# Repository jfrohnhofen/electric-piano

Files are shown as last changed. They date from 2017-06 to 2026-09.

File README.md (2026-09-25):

# Electric Piano

This repository contains the hardware and software sources for a custom electric piano project built around the ATmega16 microcontroller.

## Project Structure

The project is divided into the following main directories:

- **circuit/**: Contains the hardware design files.
  - `eagle/`: Schematics and PCB layouts designed in EAGLE.
  - `gerber/`: Manufacturing files for the PCB.
  - `parts.txt`: Bill of materials (BOM).
  - `stencil.svg`: Stencil design for solder paste application.

- **firmware/**: The C++ firmware running on the ATmega16 (16MHz).
  - `firmware.cpp`: Main application code.
  - `bootloader.cpp`: Custom bootloader.
  - `runfile`: Build and flash instructions using `avr-g++` and `avrdude` via STK500v1 over serial.

- **programer/**: A custom programmer utility written in Rust.

## Prerequisites

The easiest way to get started is by using the provided Nix flake. If you have [Nix](https://nixos.org/) installed, simply run:

```bash
nix develop
```

This will drop you into a development shell with all the required dependencies (`avr-gcc`, `avrdude`, `cargo`, `just`, etc.) installed.

If you are not using Nix, you will need to manually install:
- `avr-gcc` / `avr-g++`
- `avr-libc`
- `avrdude`
- Rust toolchain (`cargo`)
- [`just`](https://github.com/casey/just) command runner

## Building and Flashing

This project uses `just` as a command runner. You can see all available commands by running:

```bash
just --list
```

From the root directory, you can run:

- Compile the bootloader: `just bootloader`
- Compile the firmware: `just firmware`
- Flash the bootloader: `just flash-bootloader`
- Write fuses: `just write-fuses`
- Build the Rust programmer: `just build-programmer`
- Run the Rust programmer: `just run-programmer`
- Build everything: `just build-all`

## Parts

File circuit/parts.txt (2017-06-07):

Partlist

Exported from epiano.sch at 8/28/2015 8:06 PM

EAGLE Version 7.3.0 Copyright (c) 1988-2015 CadSoft

Assembly variant: 

Part     Value                Device               Package     Library  Sheet

6N138    6N138                6N138                SMD-8       epiano   1
4067     4067D                4067D                SO24W       40xx     1
C1       22pF                 C-EUC0805            C0805       epiano   1
C2       22pF                 C-EUC0805            C0805       epiano   1
C3       100nF                C-EUC0805            C0805       epiano   1
C4       47uF                 CPOL-EUD             PANASONIC_D rcl      1
C5       47uF                 CPOL-EUD             PANASONIC_D rcl      1
C6       100nF                C-EUC0805            C0805       epiano   1
C7       100nF                C-EUC0805            C0805       epiano   1
D1       1N4001               DIODE-MELF-MLL41     MELF-MLL41  diode    1
D2       1N4001               DIODE-MELF-MLL41     MELF-MLL41  diode    1
D3       1N4148               DIODE-MINIMELF       MINIMELF    diode    1
DC       DCJ0202              DCJ0202              DCJ0202     epiano   1
ISP      ISP                  PINHD-2X5_2.54-SMD   2X05SMD     epiano   1
LEFT     KBD_LEFT             PINHD-2X10_2.54-SMD  2X10SMD     epiano   1
LM1117   MC33269ST-3.3T3      MC33269ST-3.3T3      SOT223      epiano   1
MEGA16   MEGA16-A             MEGA16-A             TQFP44      atmel    1
MIDI     MAB5SH               MAB5SH               MAB5SH      epiano   1
MIDIMATE                      USBMIDI_2.54-SMD     USBMIDI     epiano   1
PEDAL    PEDAL                PINHD-2X4_2.54-SMD   2X04SMD     epiano   1
Q1       16MHz                CRYSTALSM49          SM49        crystal  1
R1       10k?                 R-EU_R0805           R0805       epiano   1
R2       220?                 R-EU_R0805           R0805       epiano   1
R3       220?                 R-EU_R0805           R0805       epiano   1
R4       220?                 R-EU_R0805           R0805       epiano   1
R5       1k?                  R-EU_R0805           R0805       epiano   1
R6       0?                   R-EU_R1206           R1206       epiano   1
RIGHT    KBD_RIGHT            PINHD-2X10_2.54-SMD  2X10SMD     epiano   1
USB      MINI-USB-UX60-MB-5ST MINI-USB-UX60-MB-5ST UX60-MB-5ST epiano   1

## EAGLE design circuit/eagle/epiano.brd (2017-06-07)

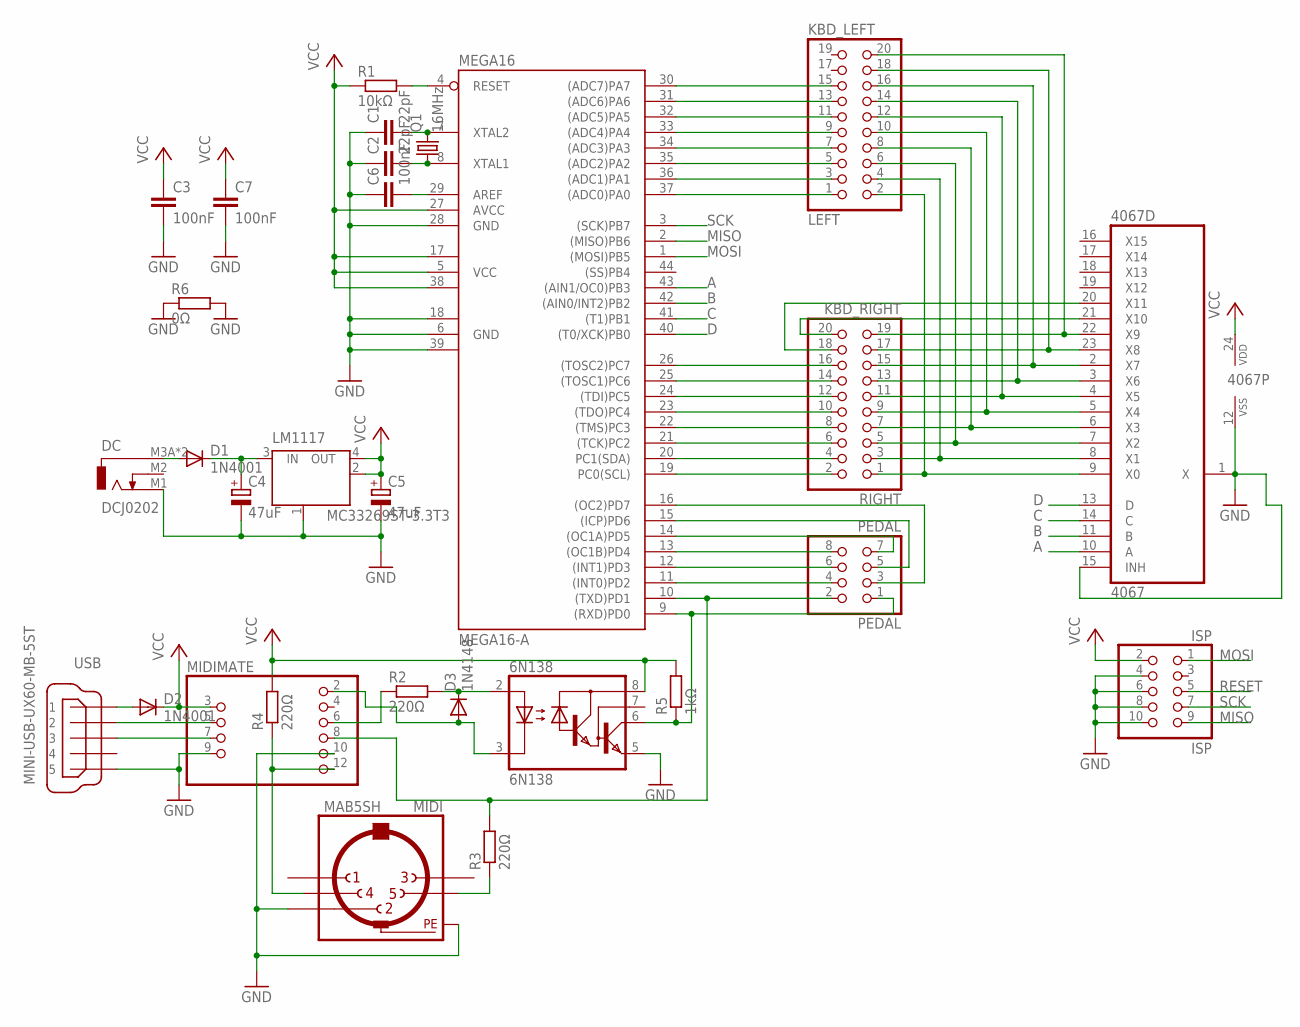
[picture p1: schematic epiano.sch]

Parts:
6N138: 6N138; SMD-8
4067: 4067D; SO24W
C1, C2: 22pF; C0805
C3, C6, C7: 100nF; C0805
C4, C5: 47uF; PANASONIC_D
D1, D2: 1N4001; MELF-MLL41
D3: 1N4148; MINIMELF
DC: DCJ0202
ISP: ISP; 2X05SMD
LEFT: KBD_LEFT; 2X10SMD
LM1117: MC33269ST-3.3T3; SOT223
MEGA16: MEGA16-A; TQFP44
MIDI: MAB5SH
MIDIMATE: USBMIDI_2.54-SMD; USBMIDI
PEDAL: PEDAL; 2X04SMD
Q1: 16MHz; SM49
R1: 10kΩ; R0805
R2, R3, R4: 220Ω; R0805
R5: 1kΩ; R0805
R6: 0Ω; R1206
RIGHT: KBD_RIGHT; 2X10SMD
USB: MINI-USB-UX60-MB-5ST; UX60-MB-5ST

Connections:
A: 4067.10 (A), MEGA16.43 ((AIN1/OC0)PB3)
B: 4067.11 (B), MEGA16.42 ((AIN0/INT2)PB2)
C: 4067.14 (C), MEGA16.41 ((T1)PB1)
D: 4067.13 (D), MEGA16.40 ((T0/XCK)PB0)
GND: 6N138.5 (GND), 4067.1 (X), 4067.12 (VSS), 4067.15 (INH), C1.1, C2.1, C3.2, C4.-, C5.-, C6.1, C7.2, DC.M1 (3), ISP.4, ISP.6, ISP.8, ISP.10, LM1117.1 (GND/ADJ), MEGA16.6 (GND), MEGA16.18 (GND1), MEGA16.28 (GND), MEGA16.39 (GND2), MIDI.2, MIDI.PE, MIDI.PE@ (PE), MIDIMATE.9, MIDIMATE.10, R6.1, R6.2, USB.5
MISO: ISP.9, MEGA16.2 ((MISO)PB6)
MOSI: ISP.1, MEGA16.1 ((MOSI)PB5)
unnamed: D2.A, USB.1
unnamed: MIDIMATE.5, USB.2
unnamed: C2.2, MEGA16.8 (XTAL1), Q1.1
unnamed: C4.+, D1.C, LM1117.3 (IN)
unnamed: MEGA16.19 (PC0(SCL)), RIGHT.2
unnamed: MEGA16.20 (PC1(SDA)), RIGHT.4
unnamed: MEGA16.21 ((TCK)PC2), RIGHT.6
unnamed: D1.A, DC.M3A (1), DC.M3B (1)
unnamed: MEGA16.22 ((TMS)PC3), RIGHT.8
unnamed: MEGA16.23 ((TDO)PC4), RIGHT.10
unnamed: MEGA16.24 ((TDI)PC5), RIGHT.12
unnamed: MEGA16.25 ((TOSC1)PC6), RIGHT.14
unnamed: MEGA16.26 ((TOSC2)PC7), RIGHT.16
unnamed: 4067.20 (X11), RIGHT.18
unnamed: LEFT.1, MEGA16.37 ((ADC0)PA0)
unnamed: LEFT.3, MEGA16.36 ((ADC1)PA1)
unnamed: LEFT.5, MEGA16.35 ((ADC2)PA2)
unnamed: LEFT.7, MEGA16.34 ((ADC3)PA3)
unnamed: LEFT.9, MEGA16.33 ((ADC4)PA4)
unnamed: LEFT.11, MEGA16.32 ((ADC5)PA5)
unnamed: LEFT.13, MEGA16.31 ((ADC6)PA6)
unnamed: LEFT.15, MEGA16.30 ((ADC7)PA7)
unnamed: 4067.21 (X10), RIGHT.20
unnamed: 4067.9 (X0), LEFT.2, RIGHT.1
unnamed: 4067.8 (X1), LEFT.4, RIGHT.3
unnamed: 4067.7 (X2), LEFT.6, RIGHT.5
unnamed: 4067.6 (X3), LEFT.8, RIGHT.7
unnamed: 4067.5 (X4), LEFT.10, RIGHT.9
unnamed: 4067.4 (X5), LEFT.12, RIGHT.11
unnamed: 4067.3 (X6), LEFT.14, RIGHT.13
unnamed: 4067.2 (X7), LEFT.16, RIGHT.15
unnamed: 4067.23 (X8), LEFT.18, RIGHT.17
unnamed: 4067.22 (X9), LEFT.20, RIGHT.19
unnamed: MEGA16.10 ((TXD)PD1), MIDIMATE.8, PEDAL.2, R3.2
unnamed: C6.2, MEGA16.29 (AREF)
unnamed: MEGA16.11 ((INT0)PD2), PEDAL.4
unnamed: MEGA16.12 ((INT1)PD3), PEDAL.6
unnamed: C1.2, MEGA16.7 (XTAL2), Q1.2
unnamed: MIDIMATE.7, USB.3
unnamed: MIDIMATE.6, R2.1
unnamed: MEGA16.13 ((OC1B)PD4), PEDAL.8
unnamed: MIDI.4, MIDIMATE.12, R4.1
unnamed: 6N138.3 (C), D3.A, MIDIMATE.2
unnamed: MEGA16.14 ((OC1A)PD5), PEDAL.7
unnamed: MEGA16.15 ((ICP)PD6), PEDAL.5
unnamed: MEGA16.16 ((OC2)PD7), PEDAL.3
unnamed: MIDI.5, R3.1
unnamed: 6N138.2 (A), D3.C, R2.2
unnamed: 6N138.6 (VO), MEGA16.9 ((RXD)PD0), PEDAL.1, R5.1
RESET: ISP.5, MEGA16.4 (RESET), R1.2
SCK: ISP.7, MEGA16.3 ((SCK)PB7)
VCC: 6N138.8 (VCC), 4067.24 (VDD), C3.1, C5.+, C7.1, D2.C, ISP.2, LM1117.2 (OUT), LM1117.4 (OUT), MEGA16.5 (VCC), MEGA16.17 (VCC1), MEGA16.27 (AVCC), MEGA16.38 (VCC2), MIDIMATE.3, R1.1, R4.2, R5.2

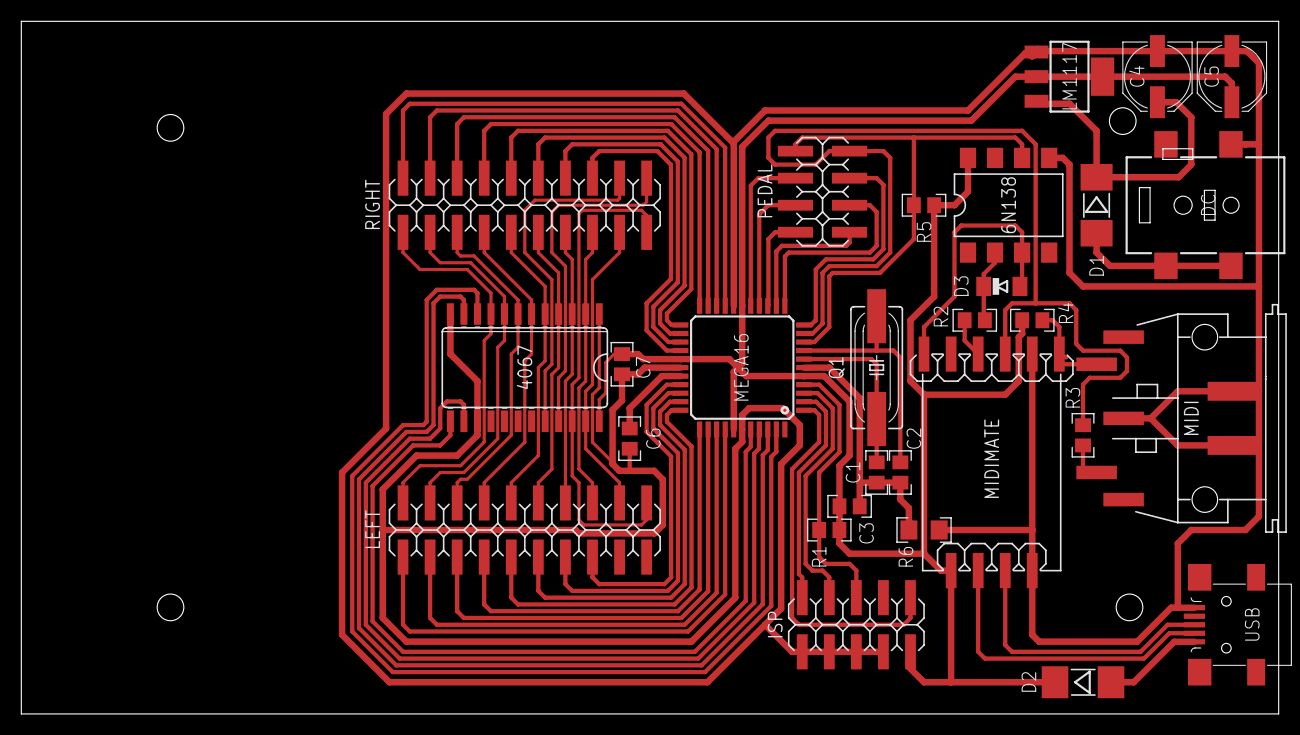
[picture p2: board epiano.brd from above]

Board: 1 copper layer, 118.0 x 65.0 mm, 29 parts (0 on the bottom side), 59 nets.

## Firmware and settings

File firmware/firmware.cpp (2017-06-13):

// The MIT License (MIT)
//
// Copyright (c) 2016 Johannes Frohnhofen
//
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
// -----------------------------------------------------------------------------
//

#include <avr/io.h>
#include <avr/interrupt.h>
#include <avr/pgmspace.h>
#include <util/delay.h>

#define MIDI_BAUD_RATE     31250

#define MIDI_A0            0x15
#define MIDI_NOTE_ON       0x90
#define MIDI_NOTE_OFF      0x80
#define MIDI_CONTROL       0xb0
#define MIDI_PROGRAM       0xc0
#define MIDI_SUSTAIN_PEDAL 0x40
#define MIDI_SOFT_PEDAL    0x43

#define SUSTAIN_PEDAL      PD3
#define SOFT_PEDAL         PD4

#define for_set_bits(BIT, VAR) \
  for(uint8_t BIT=0; VAR>0; BIT++, VAR>>=1) \
    if(VAR & 1)

#define min(a, b) ((a) < (b) ? (a) : (b))

#define KEY_INDEX(CHANNEL, LINE) (((LINE) >> 3) * 0x28 + ((CHANNEL) << 3) + ((LINE) & 0b111))

#define MIDI_KEY(CHANNEL, LINE) (MIDI_A0 + KEY_INDEX(CHANNEL, LINE))

#define READ_LINES(CHANNEL, VAR) \
  PORTB = channel_addr[(CHANNEL)]; \
  _delay_us(30); \
  VAR = (PINC << 8) | PINA;

#define HANDLE_PEDAL(PIN, COMMAND) \
  if(pedals & _BV(PIN)) { \
    uart_putc(MIDI_CONTROL); \
    uart_putc(COMMAND); \
    uart_putc((stateP & _BV(PIN)) << (6 - (PIN))); \
    _delay_ms(2); \
  }

const uint8_t channel_addr[] = {
  0b0000, 0b1000, 0b0100, 0b1100, 0b0010, 0b1010,
  0b0110, 0b1110, 0b0001, 0b1001, 0b0101, 0b1101
};

const uint8_t velocities[] PROGMEM = {
  0x7f, 0x7f, 0x7f, 0x7f, 0x7f, 0x7f, 0x7f, 0x7f, 0x7f, 0x7f, 0x7f, 0x7f, 0x7f, 0x7f, 0x7f, 0x7f,
  0x7f, 0x7f, 0x7f, 0x7f, 0x7f, 0x7f, 0x7f, 0x7f, 0x7f, 0x7f, 0x7f, 0x7f, 0x7f, 0x7f, 0x7f, 0x7e,
  0x7d, 0x7b, 0x7a, 0x78, 0x77, 0x75, 0x74, 0x73, 0x72, 0x71, 0x70, 0x6f, 0x6e, 0x6d, 0x6c, 0x6b,
  0x6a, 0x69, 0x68, 0x67, 0x66, 0x66, 0x65, 0x64, 0x63, 0x63, 0x62, 0x61, 0x61, 0x60, 0x5f, 0x5f,
  0x5e, 0x5e, 0x5d, 0x5d, 0x5c, 0x5b, 0x5b, 0x5a, 0x5a, 0x59, 0x59, 0x58, 0x58, 0x57, 0x57, 0x57,
  0x56, 0x56, 0x55, 0x55, 0x54, 0x54, 0x54, 0x53, 0x53, 0x53, 0x52, 0x52, 0x51, 0x51, 0x51, 0x50,
  0x50, 0x50, 0x4f, 0x4f, 0x4f, 0x4e, 0x4e, 0x4e, 0x4e, 0x4d, 0x4d, 0x4d, 0x4c, 0x4c, 0x4c, 0x4c,
  0x4b, 0x4b, 0x4b, 0x4a, 0x4a, 0x4a, 0x4a, 0x49, 0x49, 0x49, 0x49, 0x48, 0x48, 0x48, 0x48, 0x48,
  0x47, 0x47, 0x47, 0x47, 0x46, 0x46, 0x46, 0x46, 0x46, 0x45, 0x45, 0x45, 0x45, 0x45, 0x44, 0x44,
  0x44, 0x44, 0x44, 0x43, 0x43, 0x43, 0x43, 0x43, 0x43, 0x42, 0x42, 0x42, 0x42, 0x42, 0x41, 0x41,
  0x41, 0x41, 0x41, 0x41, 0x41, 0x40, 0x40, 0x40, 0x40, 0x40, 0x40, 0x3f, 0x3f, 0x3f, 0x3f, 0x3f,
  0x3f, 0x3f, 0x3e, 0x3e, 0x3e, 0x3e, 0x3e, 0x3e, 0x3e, 0x3d, 0x3d, 0x3d, 0x3d, 0x3d, 0x3d, 0x3d,
  0x3d, 0x3c, 0x3c, 0x3c, 0x3c, 0x3c, 0x3c, 0x3c, 0x3c, 0x3b, 0x3b, 0x3b, 0x3b, 0x3b, 0x3b, 0x3b,
  0x3b, 0x3b, 0x3a, 0x3a, 0x3a, 0x3a, 0x3a, 0x3a, 0x3a, 0x3a, 0x3a, 0x39, 0x39, 0x39, 0x39, 0x39,
  0x39, 0x39, 0x39, 0x39, 0x38, 0x38, 0x38, 0x38, 0x38, 0x38, 0x38, 0x38, 0x38, 0x38, 0x38, 0x37,
  0x37, 0x37, 0x37, 0x37, 0x37, 0x37, 0x37, 0x37, 0x37, 0x37, 0x36, 0x36, 0x36, 0x36, 0x36, 0x36,
  0x36, 0x36, 0x36, 0x36, 0x36, 0x35, 0x35, 0x35, 0x35, 0x35, 0x35, 0x35, 0x35, 0x35, 0x35, 0x35, 0x35, 0x35, 0x34, 0x34, 0x34, 0x34, 0x34, 0x34, 0x34, 0x34, 0x34, 0x34, 0x34, 0x34, 0x34, 0x33, 0x33, 0x33, 0x33, 0x33, 0x33, 0x33, 0x33, 0x33, 0x33, 0x33, 0x33, 0x33, 0x33, 0x32, 0x32, 0x32, 0x32, 0x32, 0x32, 0x32, 0x32, 0x32, 0x32, 0x32, 0x32, 0x32, 0x32, 0x32, 0x32, 0x31, 0x31, 0x31, 0x31, 0x31, 0x31, 0x31, 0x31, 0x31, 0x31, 0x31, 0x31, 0x31, 0x31, 0x31, 0x31, 0x30, 0x30, 0x30, 0x30, 0x30, 0x30, 0x30, 0x30, 0x30, 0x30, 0x30, 0x30, 0x30, 0x30, 0x30, 0x30, 0x30, 0x30, 0x2f, 0x2f, 0x2f, 0x2f, 0x2f, 0x2f, 0x2f, 0x2f, 0x2f, 0x2f, 0x2f, 0x2f, 0x2f, 0x2f, 0x2f, 0x2f, 0x2f, 0x2f, 0x2f, 0x2e, 0x2e, 0x2e, 0x2e, 0x2e, 0x2e, 0x2e, 0x2e, 0x2e, 0x2e, 0x2e, 0x2e, 0x2e, 0x2e, 0x2e, 0x2e, 0x2e, 0x2e, 0x2e, 0x2e, 0x2d, 0x2d, 0x2d, 0x2d, 0x2d, 0x2d, 0x2d, 0x2d, 0x2d, 0x2d, 0x2d, 0x2d, 0x2d, 0x2d, 0x2d, 0x2d, 0x2d, 0x2d, 0x2d, 0x2d, 0x2d, 0x2d, 0x2c, 0x2c, 0x2c, 0x2c, 0x2c, 0x2c, 0x2c, 0x2c, 0x2c, 0x2c, 0x2c, 0x2c, 0x2c, 0x2c, 0x2c, 0x2c, 0x2c, 0x2c, 0x2c, 0x2c, 0x2c, 0x2c, 0x2c, 0x2c, 0x2b, 0x2b, 0x2b, 0x2b, 0x2b, 0x2b, 0x2b, 0x2b, 0x2b, 0x2b, 0x2b, 0x2b, 0x2b, 0x2b, 0x2b, 0x2b, 0x2b, 0x2b, 0x2b, 0x2b, 0x2b, 0x2b, 0x2b, 0x2b, 0x2b, 0x2b, 0x2a, 0x2a, 0x2a, 0x2a, 0x2a, 0x2a, 0x2a, 0x2a, 0x2a, 0x2a, 0x2a, 0x2a, 0x2a, 0x2a, 0x2a, 0x2a, 0x2a, 0x2a, 0x2a, 0x2a, 0x2a, 0x2a, 0x2a, 0x2a, 0x2a, 0x2a, 0x2a, 0x29, 0x29, 0x29, 0x29, 0x29, 0x29, 0x29, 0x29, 0x29, 0x29, 0x29, 0x29, 0x29, 0x29, 0x29, 0x29, 0x29, 0x29, 0x29, 0x29, 0x29, 0x29, 0x29, 0x29, 0x29, 0x29, 0x29, 0x29, 0x29, 0x29, 0x29, 0x28, 0x28, 0x28, 0x28, 0x28, 0x28, 0x28, 0x28, 0x28, 0x28, 0x28, 0x28, 0x28, 0x28, 0x28, 0x28, 0x28, 0x28, 0x28, 0x28, 0x28, 0x28, 0x28, 0x28, 0x28, 0x28, 0x28, 0x28, 0x28, 0x28, 0x28, 0x28, 0x28, 0x27, 0x27, 0x27, 0x27, 0x27, 0x27, 0x27, 0x27, 0x27, 0x27, 0x27, 0x27, 0x27, 0x27, 0x27, 0x27, 0x27, 0x27, 0x27, 0x27, 0x27, 0x27, 0x27, 0x27, 0x27, 0x27, 0x27, 0x27, 0x27, 0x27, 0x27, 0x27, 0x27, 0x27, 0x27, 0x27, 0x26, 0x26, 0x26, 0x26, 0x26, 0x26, 0x26, 0x26, 0x26, 0x26, 0x26, 0x26, 0x26, 0x26, 0x26, 0x26, 0x26, 0x26, 0x26, 0x26, 0x26, 0x26, 0x26, 0x26, 0x26, 0x26, 0x26, 0x26, 0x26, 0x26, 0x26, 0x26, 0x26, 0x26, 0x26, 0x26, 0x26, 0x26, 0x26, 0x26, 0x25, 0x25, 0x25, 0x25, 0x25, 0x25, 0x25, 0x25, 0x25, 0x25, 0x25, 0x25, 0x25, 0x25, 0x25, 0x25, 0x25, 0x25, 0x25, 0x25, 0x25, 0x25, 0x25, 0x25, 0x25, 0x25,
  0x25, 0x25, 0x25, 0x25, 0x25, 0x25, 0x25, 0x25, 0x25, 0x25, 0x25, 0x25, 0x25, 0x25, 0x25, 0x25, 0x25, 0x24, 0x24, 0x24, 0x24, 0x24, 0x24, 0x24, 0x24, 0x24, 0x24, 0x24, 0x24, 0x24, 0x24, 0x24, 0x24, 0x24, 0x24, 0x24, 0x24, 0x24, 0x24, 0x24, 0x24, 0x24, 0x24, 0x24, 0x24, 0x24, 0x24, 0x24, 0x24, 0x24, 0x24, 0x24, 0x24, 0x24, 0x24, 0x24, 0x24, 0x24, 0x24, 0x24, 0x24, 0x24, 0x24, 0x24, 0x23, 0x23, 0x23, 0x23, 0x23, 0x23, 0x23, 0x23, 0x23, 0x23, 0x23, 0x23, 0x23, 0x23, 0x23, 0x23, 0x23, 0x23, 0x23, 0x23, 0x23, 0x23, 0x23, 0x23, 0x23, 0x23, 0x23, 0x23, 0x23, 0x23, 0x23, 0x23, 0x23, 0x23, 0x23, 0x23, 0x23, 0x23, 0x23, 0x23, 0x23, 0x23, 0x23, 0x23, 0x23, 0x23, 0x23, 0x23, 0x23, 0x23, 0x23, 0x23, 0x23, 0x22, 0x22, 0x22, 0x22, 0x22, 0x22, 0x22, 0x22, 0x22, 0x22, 0x22, 0x22, 0x22, 0x22, 0x22, 0x22, 0x22, 0x22, 0x22, 0x22, 0x22, 0x22, 0x22, 0x22, 0x22, 0x22, 0x22, 0x22, 0x22, 0x22, 0x22, 0x22, 0x22, 0x22, 0x22, 0x22, 0x22, 0x22, 0x22, 0x22, 0x22, 0x22, 0x22, 0x22, 0x22, 0x22, 0x22, 0x22, 0x22, 0x22, 0x22, 0x22, 0x22, 0x22, 0x22, 0x22, 0x22, 0x22, 0x21, 0x21, 0x21, 0x21, 0x21, 0x21, 0x21, 0x21, 0x21, 0x21, 0x21, 0x21, 0x21, 0x21, 0x21, 0x21, 0x21, 0x21, 0x21, 0x21, 0x21, 0x21, 0x21, 0x21, 0x21, 0x21, 0x21, 0x21, 0x21, 0x21, 0x21, 0x21, 0x21, 0x21, 0x21, 0x21, 0x21, 0x21, 0x21, 0x21, 0x21, 0x21, 0x21, 0x21, 0x21, 0x21, 0x21, 0x21, 0x21, 0x21, 0x21, 0x21, 0x21, 0x21, 0x21, 0x21, 0x21, 0x21, 0x21, 0x21, 0x21, 0x21, 0x21, 0x21, 0x20, 0x20, 0x20, 0x20, 0x20, 0x20, 0x20, 0x20, 0x20, 0x20, 0x20, 0x20, 0x20, 0x20, 0x20, 0x20, 0x20, 0x20, 0x20, 0x20, 0x20, 0x20, 0x20, 0x20, 0x20, 0x20, 0x20, 0x20, 0x20, 0x20, 0x20, 0x20, 0x20, 0x20, 0x20, 0x20, 0x20, 0x20, 0x20, 0x20, 0x20, 0x20, 0x20, 0x20, 0x20, 0x20, 0x20, 0x20, 0x20, 0x20, 0x20, 0x20, 0x20, 0x20, 0x20, 0x20, 0x20, 0x20, 0x20, 0x20, 0x20, 0x20, 0x20, 0x20, 0x20, 0x20, 0x20, 0x20, 0x20, 0x20, 0x20, 0x20, 0x1f, 0x1f, 0x1f, 0x1f, 0x1f, 0x1f, 0x1f, 0x1f, 0x1f, 0x1f, 0x1f, 0x1f, 0x1f, 0x1f, 0x1f, 0x1f, 0x1f, 0x1f, 0x1f, 0x1f, 0x1f, 0x1f, 0x1f, 0x1f, 0x1f, 0x1f, 0x1f, 0x1f, 0x1f, 0x1f, 0x1f, 0x1f, 0x1f, 0x1f, 0x1f, 0x1f, 0x1f, 0x1f, 0x1f, 0x1f, 0x1f, 0x1f, 0x1f, 0x1f, 0x1f, 0x1f, 0x1f, 0x1f, 0x1f, 0x1f, 0x1f, 0x1f, 0x1f, 0x1f, 0x1f, 0x1f, 0x1f, 0x1f, 0x1f, 0x1f, 0x1f, 0x1f, 0x1f, 0x1f, 0x1f, 0x1f, 0x1f, 0x1f, 0x1f, 0x1f, 0x1f, 0x1f, 0x1f, 0x1f, 0x1f, 0x1f, 0x1f, 0x1f, 0x1f, 0x1e, 0x1e, 0x1e, 0x1e, 0x1e, 0x1e, 0x1e, 0x1e, 0x1e, 0x1e, 0x1e, 0x1e, 0x1e, 0x1e, 0x1e, 0x1e, 0x1e, 0x1e, 0x1e, 0x1e, 0x1e, 0x1e, 0x1e, 0x1e, 0x1e, 0x1e, 0x1e, 0x1e, 0x1e, 0x1e, 0x1e, 0x1e, 0x1e, 0x1e, 0x1e, 0x1e, 0x1e, 0x1e, 0x1e, 0x1e, 0x1e, 0x1e, 0x1e, 0x1e, 0x1e, 0x1e, 0x1e, 0x1e, 0x1e, 0x1e, 0x1e, 0x1e, 0x1e, 0x1e, 0x1e, 0x1e, 0x1e, 0x1e, 0x1e, 0x1e, 0x1e, 0x1e, 0x1e, 0x1e, 0x1e, 0x1e, 0x1e, 0x1e, 0x1e, 0x1e, 0x1e, 0x1e, 0x1e, 0x1e, 0x1e, 0x1e, 0x1e, 0x1e, 0x1e, 0x1e, 0x1e, 0x1e, 0x1e, 0x1e, 0x1e, 0x1e, 0x1e, 0x1e, 0x1e, 0x1e, 0x1d, 0x1d, 0x1d, 0x1d, 0x1d, 0x1d, 0x1d, 0x1d, 0x1d, 0x1d, 0x1d, 0x1d, 0x1d, 0x1d, 0x1d, 0x1d, 0x1d, 0x1d, 0x1d, 0x1d, 0x1d, 0x1d, 0x1d, 0x1d, 0x1d, 0x1d, 0x1d, 0x1d, 0x1d, 0x1d, 0x1d, 0x1d, 0x1d, 0x1d, 0x1d, 0x1d, 0x1d, 0x1d, 0x1d, 0x1d, 0x1d, 0x1d, 0x1d, 0x1d, 0x1d, 0x1d, 0x1d, 0x1d, 0x1d, 0x1d, 0x1d, 0x1d, 0x1d, 0x1d, 0x1d, 0x1d, 0x1d, 0x1d, 0x1d, 0x1d, 0x1d, 0x1d, 0x1d, 0x1d, 0x1d, 0x1d, 0x1d, 0x1d, 0x1d, 0x1d, 0x1d, 0x1d, 0x1d, 0x1d, 0x1d, 0x1d, 0x1d, 0x1d, 0x1d, 0x1d, 0x1d, 0x1d, 0x1d, 0x1d, 0x1d, 0x1d, 0x1d, 0x1d, 0x1d, 0x1d, 0x1d, 0x1d, 0x1d, 0x1d, 0x1d, 0x1d, 0x1d, 0x1d, 0x1d, 0x1d, 0x1c, 0x1c, 0x1c, 0x1c, 0x1c, 0x1c, 0x1c, 0x1c, 0x1c, 0x1c, 0x1c, 0x1c, 0x1c, 0x1c, 0x1c, 0x1c, 0x1c, 0x1c, 0x1c, 0x1c, 0x1c, 0x1c, 0x1c, 0x1c, 0x1c, 0x1c, 0x1c, 0x1c, 0x1c, 0x1c, 0x1c, 0x1c, 0x1c, 0x1c, 0x1c, 0x1c, 0x1c, 0x1c, 0x1c, 0x1c, 0x1c, 0x1c, 0x1c, 0x1c, 0x1c, 0x1c, 0x1c, 0x1c, 0x1c, 0x1c, 0x1c, 0x1c, 0x1c, 0x1c, 0x1c, 0x1c, 0x1c, 0x1c, 0x1c, 0x1c, 0x1c, 0x1c, 0x1c, 0x1c, 0x1c, 0x1c, 0x1c, 0x1c, 0x1c, 0x1c, 0x1c, 0x1c, 0x1c, 0x1c, 0x1c, 0x1c, 0x1c, 0x1c, 0x1c, 0x1c, 0x1c, 0x1c, 0x1c, 0x1c, 0x1c, 0x1c, 0x1c, 0x1c, 0x1c, 0x1c, 0x1c, 0x1c, 0x1c, 0x1c, 0x1c, 0x1c, 0x1c, 0x1c, 0x1c, 0x1c, 0x1c, 0x1c, 0x1c, 0x1c, 0x1c, 0x1c, 0x1c, 0x1c, 0x1c, 0x1c, 0x1c, 0x1c, 0x1c, 0x1b, 0x1b, 0x1b, 0x1b, 0x1b, 0x1b, 0x1b, 0x1b, 0x1b, 0x1b, 0x1b, 0x1b, 0x1b, 0x1b, 0x1b, 0x1b, 0x1b, 0x1b, 0x1b, 0x1b, 0x1b, 0x1b, 0x1b, 0x1b, 0x1b, 0x1b, 0x1b, 0x1b, 0x1b, 0x1b, 0x1b, 0x1b, 0x1b, 0x1b, 0x1b, 0x1b, 0x1b, 0x1b, 0x1b, 0x1b, 0x1b, 0x1b, 0x1b, 0x1b, 0x1b, 0x1b, 0x1b, 0x1b, 0x1b, 0x1b, 0x1b, 0x1b, 0x1b, 0x1b, 0x1b, 0x1b, 0x1b, 0x1b, 0x1b, 0x1b, 0x1b, 0x1b, 0x1b, 0x1b, 0x1b, 0x1b, 0x1b, 0x1b, 0x1b, 0x1b, 0x1b, 0x1b, 0x1b, 0x1b, 0x1b, 0x1b, 0x1b, 0x1b, 0x1b, 0x1b, 0x1b, 0x1b, 0x1b, 0x1b, 0x1b, 0x1b, 0x1b, 0x1b, 0x1b, 0x1b, 0x1b, 0x1b, 0x1b, 0x1b, 0x1b, 0x1b, 0x1b, 0x1b, 0x1b, 0x1b, 0x1b, 0x1b, 0x1b, 0x1b, 0x1b, 0x1b, 0x1b, 0x1b, 0x1b, 0x1b, 0x1b, 0x1b, 0x1b, 0x1b, 0x1b, 0x1b, 0x1b, 0x1b, 0x1b, 0x1b, 0x1b, 0x1b, 0x1b, 0x1b, 0x1b, 0x1b, 0x1b, 0x1b, 0x1a, 0x1a, 0x1a, 0x1a, 0x1a, 0x1a, 0x1a, 0x1a, 0x1a, 0x1a, 0x1a, 0x1a, 0x1a, 0x1a, 0x1a, 0x1a, 0x1a, 0x1a, 0x1a, 0x1a, 0x1a, 0x1a, 0x1a, 0x1a, 0x1a, 0x1a, 0x1a, 0x1a, 0x1a, 0x1a, 0x1a, 0x1a, 0x1a, 0x1a, 0x1a, 0x1a, 0x1a, 0x1a, 0x1a, 0x1a, 0x1a, 0x1a, 0x1a, 0x1a, 0x1a, 0x1a, 0x1a, 0x1a, 0x1a, 0x1a, 0x1a, 0x1a, 0x1a, 0x1a, 0x1a, 0x1a, 0x1a, 0x1a, 0x1a, 0x1a, 0x1a, 0x1a, 0x1a, 0x1a, 0x1a, 0x1a, 0x1a, 0x1a, 0x1a, 0x1a, 0x1a, 0x1a, 0x1a, 0x1a, 0x1a, 0x1a, 0x1a, 0x1a, 0x1a, 0x1a, 0x1a, 0x1a, 0x1a, 0x1a, 0x1a, 0x1a, 0x1a, 0x1a, 0x1a, 0x1a, 0x1a, 0x1a, 0x1a, 0x1a, 0x1a, 0x1a, 0x1a, 0x1a, 0x1a, 0x1a, 0x1a, 0x1a, 0x1a, 0x1a, 0x1a, 0x1a, 0x1a, 0x1a, 0x1a, 0x1a, 0x1a, 0x1a, 0x1a, 0x1a, 0x1a, 0x1a, 0x1a, 0x1a, 0x1a, 0x1a, 0x1a, 0x1a, 0x1a, 0x1a, 0x1a, 0x1a, 0x1a, 0x1a, 0x1a, 0x1a, 0x1a, 0x1a, 0x1a, 0x1a, 0x1a, 0x1a, 0x1a, 0x1a, 0x1a, 0x1a, 0x1a, 0x1a, 0x1a, 0x1a, 0x1a, 0x1a, 0x19, 0x19, 0x19, 0x19, 0x19, 0x19, 0x19, 0x19, 0x19, 0x19, 0x19, 0x19, 0x19, 0x19, 0x19, 0x19, 0x19, 0x19, 0x19, 0x19, 0x19, 0x19, 0x19, 0x19, 0x19, 0x19, 0x19, 0x19, 0x19, 0x19, 0x19, 0x19, 0x19, 0x19, 0x19, 0x19, 0x19, 0x19, 0x19, 0x19, 0x19, 0x19, 0x19, 0x19, 0x19, 0x19, 0x19, 0x19, 0x19, 0x19, 0x19, 0x19, 0x19, 0x19, 0x19, 0x19, 0x19, 0x19, 0x19, 0x19, 0x19, 0x19, 0x19, 0x19, 0x19, 0x19, 0x19, 0x19, 0x19, 0x19, 0x19, 0x19, 0x19, 0x19, 0x19, 0x19, 0x19, 0x19, 0x19, 0x19, 0x19, 0x19, 0x19, 0x19, 0x19, 0x19, 0x19, 0x19, 0x19, 0x19, 0x19, 0x19, 0x19, 0x19, 0x19, 0x19, 0x19, 0x19, 0x19, 0x19, 0x19, 0x19, 0x19, 0x19, 0x19, 0x19, 0x19, 0x19, 0x19, 0x19, 0x19, 0x19, 0x19, 0x19, 0x19, 0x19, 0x19, 0x19, 0x19, 0x19, 0x19, 0x19, 0x19, 0x19, 0x19, 0x19, 0x19, 0x19, 0x19, 0x19, 0x19, 0x19, 0x19, 0x19, 0x19, 0x19, 0x19, 0x19, 0x19, 0x19, 0x19, 0x19, 0x19, 0x19, 0x19, 0x19, 0x19, 0x19, 0x19, 0x19, 0x19, 0x19, 0x19, 0x19, 0x19, 0x19, 0x19, 0x19, 0x19, 0x19, 0x19, 0x19, 0x19, 0x19, 0x19, 0x19, 0x19, 0x18, 0x18, 0x18, 0x18, 0x18, 0x18, 0x18, 0x18, 0x18, 0x18, 0x18, 0x18, 0x18, 0x18, 0x18, 0x18, 0x18, 0x18, 0x18, 0x18, 0x18, 0x18, 0x18, 0x18, 0x18, 0x18, 0x18, 0x18, 0x18, 0x18, 0x18, 0x18, 0x18, 0x18, 0x18, 0x18, 0x18, 0x18, 0x18, 0x18, 0x18, 0x18, 0x18, 0x18, 0x18, 0x18, 0x18, 0x18, 0x18, 0x18, 0x18, 0x18, 0x18, 0x18, 0x18, 0x18, 0x18, 0x18, 0x18, 0x18, 0x18, 0x18, 0x18, 0x18, 0x18, 0x18, 0x18, 0x18, 0x18, 0x18, 0x18, 0x18, 0x18, 0x18, 0x18, 0x18, 0x18, 0x18, 0x18, 0x18, 0x18, 0x18, 0x18, 0x18, 0x18, 0x18, 0x18, 0x18, 0x18, 0x18, 0x18, 0x18, 0x18, 0x18, 0x18, 0x18, 0x18, 0x18, 0x18, 0x18, 0x18, 0x18, 0x18, 0x18, 0x18, 0x18, 0x18, 0x18, 0x18, 0x18, 0x18, 0x18, 0x18, 0x18, 0x18, 0x18, 0x18, 0x18, 0x18, 0x18, 0x18, 0x18, 0x18, 0x18, 0x18, 0x18, 0x18, 0x18, 0x18, 0x18, 0x18, 0x18, 0x18, 0x18, 0x18, 0x18, 0x18, 0x18, 0x18, 0x18, 0x18, 0x18, 0x18, 0x18, 0x18, 0x18, 0x18, 0x18, 0x18, 0x18, 0x18, 0x18, 0x18, 0x18, 0x18, 0x18, 0x18, 0x18, 0x18, 0x18, 0x18, 0x18, 0x18, 0x18, 0x18, 0x18, 0x18, 0x18, 0x18, 0x18, 0x18, 0x18, 0x18, 0x18, 0x18, 0x18, 0x18, 0x18, 0x18, 0x18, 0x18, 0x18, 0x18, 0x18, 0x18, 0x18, 0x18, 0x18, 0x18, 0x18, 0x18, 0x18, 0x18, 0x17, 0x17, 0x17, 0x17, 0x17, 0x17, 0x17, 0x17, 0x17, 0x17, 0x17, 0x17, 0x17, 0x17, 0x17, 0x17, 0x17, 0x17, 0x17, 0x17, 0x17, 0x17, 0x17, 0x17, 0x17, 0x17, 0x17, 0x17, 0x17, 0x17, 0x17, 0x17, 0x17, 0x17, 0x17, 0x17, 0x17, 0x17, 0x17, 0x17, 0x17, 0x17, 0x17, 0x17, 0x17, 0x17, 0x17, 0x17, 0x17, 0x17, 0x17, 0x17, 0x17, 0x17, 0x17, 0x17, 0x17, 0x17, 0x17, 0x17, 0x17, 0x17, 0x17, 0x17, 0x17, 0x17, 0x17, 0x17, 0x17, 0x17, 0x17, 0x17, 0x17, 0x17, 0x17, 0x17, 0x17, 0x17, 0x17, 0x17, 0x17, 0x17, 0x17, 0x17, 0x17, 0x17, 0x17, 0x17, 0x17, 0x17, 0x17, 0x17, 0x17, 0x17, 0x17, 0x17, 0x17, 0x17, 0x17, 0x17, 0x17, 0x17, 0x17, 0x17, 0x17, 0x17, 0x17, 0x17, 0x17, 0x17, 0x17, 0x17, 0x17, 0x17, 0x17, 0x17, 0x17, 0x17, 0x17, 0x17, 0x17, 0x17, 0x17, 0x17, 0x17, 0x17, 0x17, 0x17, 0x17, 0x17, 0x17, 0x17, 0x17, 0x17, 0x17, 0x17, 0x17, 0x17, 0x17, 0x17, 0x17, 0x17, 0x17, 0x17, 0x17, 0x17, 0x17, 0x17, 0x17, 0x17, 0x17, 0x17, 0x17, 0x17, 0x17, 0x17, 0x17, 0x17, 0x17, 0x17, 0x17, 0x17, 0x17, 0x17, 0x17, 0x17, 0x17, 0x17, 0x17, 0x17, 0x17, 0x17, 0x17, 0x17, 0x17, 0x17, 0x17, 0x17, 0x17, 0x17, 0x17, 0x17, 0x17, 0x17, 0x17, 0x17, 0x17, 0x17, 0x17, 0x17, 0x17, 0x17, 0x17, 0x17, 0x17, 0x17, 0x17, 0x17, 0x17, 0x17, 0x17, 0x17, 0x17, 0x17, 0x17, 0x17, 0x17, 0x17, 0x17, 0x17, 0x17, 0x17, 0x17, 0x17, 0x17, 0x17, 0x17, 0x17, 0x17, 0x17, 0x17, 0x17, 0x16, 0x16, 0x16, 0x16, 0x16, 0x16, 0x16, 0x16, 0x16, 0x16, 0x16, 0x16, 0x16, 0x16, 0x16, 0x16, 0x16, 0x16, 0x16, 0x16, 0x16, 0x16, 0x16, 0x16, 0x16, 0x16, 0x16, 0x16, 0x16, 0x16, 0x16, 0x16, 0x16, 0x16, 0x16, 0x16, 0x16, 0x16, 0x16, 0x16, 0x16, 0x16, 0x16, 0x16, 0x16, 0x16, 0x16, 0x16, 0x16, 0x16, 0x16, 0x16, 0x16, 0x16, 0x16, 0x16, 0x16, 0x16, 0x16, 0x16, 0x16, 0x16, 0x16, 0x16, 0x16, 0x16, 0x16, 0x16, 0x16, 0x16, 0x16, 0x16, 0x16, 0x16, 0x16, 0x16, 0x16, 0x16, 0x16, 0x16, 0x16, 0x16, 0x16, 0x16, 0x16, 0x16, 0x16, 0x16, 0x16, 0x16, 0x16, 0x16, 0x16, 0x16, 0x16, 0x16, 0x16, 0x16, 0x16, 0x16, 0x16, 0x16, 0x16, 0x16, 0x16, 0x16, 0x16, 0x16, 0x16, 0x16, 0x16, 0x16, 0x16, 0x16, 0x16, 0x16, 0x16, 0x16, 0x16, 0x16, 0x16, 0x16, 0x16, 0x16, 0x16, 0x16, 0x16, 0x16, 0x16, 0x16, 0x16, 0x16, 0x16, 0x16, 0x16, 0x16, 0x16, 0x16, 0x16, 0x16, 0x16, 0x16, 0x16, 0x16, 0x16, 0x16, 0x16, 0x16, 0x16, 0x16, 0x16, 0x16, 0x16, 0x16, 0x16, 0x16, 0x16, 0x16, 0x16, 0x16, 0x16, 0x16, 0x16, 0x16, 0x16, 0x16, 0x16, 0x16, 0x16, 0x16, 0x16, 0x16, 0x16, 0x16, 0x16, 0x16, 0x16, 0x16, 0x16, 0x16, 0x16, 0x16, 0x16, 0x16, 0x16, 0x16, 0x16, 0x16, 0x16, 0x16, 0x16, 0x16, 0x16, 0x16, 0x16, 0x16, 0x16, 0x16, 0x16, 0x16, 0x16, 0x16, 0x16, 0x16, 0x16, 0x16, 0x16, 0x16, 0x16, 0x16, 0x16, 0x16, 0x16, 0x16, 0x16, 0x16, 0x16, 0x16, 0x16, 0x16, 0x16, 0x16, 0x16, 0x16, 0x16, 0x16, 0x16, 0x16, 0x16, 0x16, 0x16, 0x16, 0x16, 0x16, 0x16, 0x16, 0x16, 0x16, 0x16, 0x16, 0x16, 0x16, 0x16, 0x16, 0x16, 0x16, 0x16, 0x16, 0x16, 0x16, 0x16, 0x16, 0x16, 0x16, 0x16, 0x16, 0x16, 0x16, 0x16, 0x15, 0x15, 0x15, 0x15, 0x15, 0x15, 0x15, 0x15, 0x15, 0x15, 0x15, 0x15, 0x15, 0x15, 0x15, 0x15, 0x15, 0x15, 0x15, 0x15, 0x15, 0x15, 0x15, 0x15, 0x15, 0x15, 0x15, 0x15, 0x15, 0x15, 0x15, 0x15, 0x15, 0x15, 0x15, 0x15, 0x15, 0x15, 0x15, 0x15, 0x15, 0x15, 0x15, 0x15, 0x15, 0x15, 0x15, 0x15, 0x15, 0x15, 0x15, 0x15, 0x15, 0x15, 0x15, 0x15, 0x15, 0x15, 0x15, 0x15, 0x15, 0x15, 0x15, 0x15, 0x15, 0x15, 0x15, 0x15, 0x15, 0x15, 0x15, 0x15, 0x15, 0x15, 0x15, 0x15, 0x15, 0x15, 0x15, 0x15, 0x15, 0x15, 0x15, 0x15, 0x15, 0x15, 0x15, 0x15, 0x15, 0x15, 0x15, 0x15, 0x15, 0x15, 0x15, 0x15, 0x15, 0x15, 0x15, 0x15, 0x15, 0x15, 0x15, 0x15, 0x15, 0x15, 0x15, 0x15, 0x15, 0x15, 0x15, 0x15, 0x15, 0x15, 0x15, 0x15, 0x15, 0x15, 0x15, 0x15, 0x15, 0x15, 0x15, 0x15, 0x15, 0x15, 0x15, 0x15, 0x15, 0x15, 0x15, 0x15, 0x15, 0x15, 0x15, 0x15, 0x15, 0x15, 0x15, 0x15, 0x15, 0x15, 0x15, 0x15, 0x15, 0x15, 0x15, 0x15, 0x15, 0x15, 0x15, 0x15, 0x15, 0x15, 0x15, 0x15, 0x15, 0x15, 0x15, 0x15, 0x15, 0x15, 0x15, 0x15, 0x15, 0x15, 0x15, 0x15, 0x15, 0x15, 0x15, 0x15, 0x15, 0x15, 0x15, 0x15, 0x15, 0x15, 0x15, 0x15, 0x15, 0x15, 0x15, 0x15, 0x15, 0x15, 0x15, 0x15, 0x15, 0x15, 0x15, 0x15, 0x15, 0x15, 0x15, 0x15, 0x15, 0x15, 0x15, 0x15, 0x15, 0x15, 0x15, 0x15, 0x15, 0x15, 0x15, 0x15, 0x15, 0x15, 0x15, 0x15, 0x15, 0x15, 0x15, 0x15, 0x15, 0x15, 0x15, 0x15, 0x15, 0x15, 0x15, 0x15, 0x15, 0x15, 0x15, 0x15, 0x15, 0x15, 0x15, 0x15, 0x15, 0x15, 0x15, 0x15, 0x15, 0x15, 0x15, 0x15, 0x15, 0x15, 0x15, 0x15, 0x15, 0x15, 0x15, 0x15, 0x15, 0x15, 0x15, 0x15, 0x15, 0x15, 0x15, 0x15, 0x15, 0x15, 0x15, 0x15, 0x15, 0x15, 0x15, 0x15, 0x15, 0x15, 0x15, 0x15, 0x15, 0x15, 0x15, 0x15, 0x15, 0x15, 0x15, 0x15, 0x15, 0x15, 0x15, 0x15, 0x15, 0x15, 0x15, 0x15, 0x15, 0x15, 0x15, 0x15, 0x15, 0x15, 0x15, 0x15, 0x15, 0x15, 0x15, 0x15, 0x15, 0x15, 0x15, 0x15, 0x15, 0x15, 0x15, 0x15, 0x14, 0x14, 0x14, 0x14, 0x14, 0x14, 0x14, 0x14, 0x14, 0x14, 0x14, 0x14, 0x14, 0x14, 0x14, 0x14, 0x14, 0x14, 0x14, 0x14, 0x14, 0x14, 0x14, 0x14, 0x14, 0x14, 0x14, 0x14, 0x14, 0x14, 0x14, 0x14, 0x14, 0x14, 0x14, 0x14, 0x14, 0x14, 0x14, 0x14, 0x14, 0x14, 0x14, 0x14, 0x14, 0x14, 0x14, 0x14, 0x14, 0x14, 0x14, 0x14, 0x14, 0x14, 0x14, 0x14, 0x14, 0x14, 0x14, 0x14, 0x14, 0x14, 0x14, 0x14, 0x14, 0x14, 0x14, 0x14, 0x14, 0x14, 0x14, 0x14, 0x14, 0x14, 0x14, 0x14, 0x14, 0x14, 0x14, 0x14, 0x14, 0x14, 0x14, 0x14, 0x14, 0x14, 0x14, 0x14, 0x14, 0x14, 0x14, 0x14, 0x14, 0x14, 0x14, 0x14, 0x14, 0x14, 0x14, 0x14, 0x14, 0x14, 0x14, 0x14, 0x14, 0x14, 0x14, 0x14, 0x14, 0x14, 0x14, 0x14, 0x14, 0x14, 0x14, 0x14, 0x14, 0x14, 0x14, 0x14, 0x14, 0x14, 0x14, 0x14, 0x14, 0x14, 0x14, 0x14, 0x14, 0x14, 0x14, 0x14, 0x14, 0x14, 0x14, 0x14, 0x14, 0x14, 0x14, 0x14, 0x14, 0x14, 0x14, 0x14, 0x14, 0x14, 0x14, 0x14, 0x14, 0x14, 0x14, 0x14, 0x14, 0x14, 0x14, 0x14, 0x14, 0x14, 0x14, 0x14, 0x14, 0x14, 0x14, 0x14, 0x14, 0x14, 0x14, 0x14, 0x14, 0x14, 0x14, 0x14, 0x14, 0x14, 0x14, 0x14, 0x14, 0x14, 0x14, 0x14, 0x14, 0x14, 0x14, 0x14, 0x14, 0x14, 0x14, 0x14, 0x14, 0x14, 0x14, 0x14, 0x14, 0x14, 0x14, 0x14, 0x14, 0x14, 0x14, 0x14, 0x14, 0x14, 0x14, 0x14, 0x14, 0x14, 0x14, 0x14, 0x14, 0x14, 0x14, 0x14, 0x14, 0x14, 0x14, 0x14, 0x14, 0x14, 0x14, 0x14, 0x14, 0x14, 0x14, 0x14, 0x14, 0x14, 0x14, 0x14, 0x14, 0x14, 0x14, 0x14, 0x14, 0x14, 0x14, 0x14, 0x14, 0x14, 0x14, 0x14, 0x14, 0x14, 0x14, 0x14, 0x14, 0x14, 0x14, 0x14, 0x14, 0x14, 0x14, 0x14, 0x14, 0x14, 0x14, 0x14, 0x14, 0x14, 0x14, 0x14, 0x14, 0x14, 0x14, 0x14, 0x14, 0x14, 0x14, 0x14, 0x14, 0x14, 0x14, 0x14, 0x14, 0x14, 0x14, 0x14, 0x14, 0x14, 0x14, 0x14, 0x14, 0x14, 0x14, 0x14, 0x14, 0x14, 0x14, 0x14, 0x14, 0x14, 0x14, 0x14, 0x14, 0x14, 0x14, 0x14, 0x14, 0x14, 0x14, 0x14, 0x14, 0x14, 0x14, 0x14, 0x14, 0x14, 0x14, 0x14, 0x14, 0x14, 0x14, 0x14, 0x14, 0x14, 0x14, 0x14, 0x14, 0x14, 0x14, 0x14, 0x14, 0x14, 0x14, 0x14, 0x14, 0x14, 0x14, 0x14, 0x14, 0x14, 0x14, 0x14, 0x14, 0x14, 0x14, 0x14, 0x14, 0x14, 0x14, 0x14, 0x14, 0x14, 0x14, 0x14, 0x14, 0x14, 0x14, 0x14, 0x14, 0x14, 0x14, 0x14, 0x14, 0x14, 0x14, 0x14, 0x14, 0x14, 0x13, 0x13, 0x13, 0x13, 0x13, 0x13, 0x13, 0x13, 0x13, 0x13, 0x13, 0x13, 0x13, 0x13, 0x13, 0x13,
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
int main()
{
  uint16_t stateA[6], stateB[6];
  uint16_t inputA, inputB;
  uint16_t timer, note_on, note_off;
  uint16_t timestamp;
  uint16_t timers[96];

  uint8_t stateP;
  uint8_t inputP;
  uint8_t pedals;

  // set PORTA and PORTC as input with pullup
  DDRA  = 0x00;
  PORTA = 0xff;
  DDRC  = 0x00;
  PORTC = 0xff;

  // set PORTB0-3 as output
  DDRB = 0x0f;

  DDRD  = _BV(PD5);
  PORTD = _BV(PD3) | _BV(PD4);

  // set timer1 pre-scaler to 1024
  TCCR1B = (1 << CS12) | (1 << CS10);

  uart_init();

  for(;;) {

    for(uint8_t chan = 0; chan < 6; chan++) {

      READ_LINES(chan << 1, inputA);
      READ_LINES((chan << 1) + 1, inputB);

      // time measurements
      timer = (stateA[chan] ^ ~stateB[chan]) & (inputA ^ inputB | stateA[chan] ^ inputA);
      timestamp = TCNT1;

      for_set_bits(line, timer) {
        timers[KEY_INDEX(chan, line)] = timestamp;
      }

      // output notes
      note_on = stateB[chan] & ~inputA & ~inputB;
      note_off = ~stateB[chan] & inputA & inputB;

      for_set_bits(line, note_on) {
        uint16_t touch_duration = timestamp - timers[KEY_INDEX(chan, line)];
        touch_duration = min(touch_duration, sizeof(velocities) - 1);
        uint8_t velocity = pgm_read_byte(&(velocities[touch_duration]));
        midi_note_on(MIDI_KEY(chan, line), 100);
      }

      for_set_bits(line, note_off) {
        midi_note_off(MIDI_KEY(chan, line));
      }

      // update states
      stateA[chan] = inputB | (~stateB[chan] & inputA);
      stateB[chan] = stateA[chan] ^ inputA ^ inputB;
    }

    inputP = PIND;
    pedals = inputP ^ stateP;

    HANDLE_PEDAL(SUSTAIN_PEDAL, MIDI_SUSTAIN_PEDAL)
    HANDLE_PEDAL(SOFT_PEDAL, MIDI_SOFT_PEDAL)

    stateP = inputP;
  }
}

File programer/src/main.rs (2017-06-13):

extern crate portmidi as pm;

extern crate sysexprog;

use sysexprog::command::*;

fn main() {
    //  let context = pm::PortMidi::new().unwrap();

    /*  let device_id = 3;
  hallo();
  context
    .device(device_id)
    .and_then(|dev| context.output_port(dev, 1024))
    .and_then(|port| port.write_sysex(0, &[240, 0, 112, 1, 1, 0, 1, 0, 247])).unwrap();
*/

    let ping = Ping {};
    print!("{:?}", ping.to_sysex());
}
